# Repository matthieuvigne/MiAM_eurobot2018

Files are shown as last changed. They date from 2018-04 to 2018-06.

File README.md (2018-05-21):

# MiAM_eurobot2018
## Electronics and code of MiAM's robot for Eurobot 2018.

2018 was the first year of MiAM, a French team of former students from MINES ParisTech and Arts et Métiers schools. The team ranked 20th in the Coupe de France. 

See [MiAM website](https://www.miam-robotique.fr/) (in French).

### Contents
 - **Electronics**: component list, PCB and wiring diagram. 
 - **Code_BBB**: the robot code, running on the robot Beaglebone Black processor.

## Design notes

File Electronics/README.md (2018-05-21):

# Electronics Folder

This folder contains files related to the robot electronics: PCB and wiring.

For PCB creation, the free software  [Designspark 8.0](https://www.rs-online.com/designspark/pcb-download-and-installation) was used.

### GlobalArchitecture

A global electrical diagram of the robot, showing the full architecture. All the components are represented, along with wiring links between them.

### Libraries
This folder contains two PCB component libraries used in the main PCB:
 - pinheader : this library contains many footprints for 2.54mm-spaced standard pin headers.
 - Eurobot : a miscellaneous library containing all the custom components used, or that  had been used for previous PCB for Eurobot.
 
To add these libraries to Designspark, go to Libraries (Ctrl + L), Folders, Add and add the path to the Libraries folder.

### BeageboneCape

This is the main (and only) PCB realized this year. It is a cape covering the Beaglebone (like an Arduino shield), responsible for all the interface between the Beaglebone
and the other components, as well as power distribution. See BeagleboneCape.sch and BeagleboneCape.pcb for schematic and layout, respectively.

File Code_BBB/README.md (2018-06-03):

# Code_BBB
This folder contains all the code of the on-board Beaglebone of the robot.
This code, written entirely in C, is organished around a library, named BBBEurobot, that implements all low-level
functionalities needed to use the robot (mainly sensor and motor communication handling, and GPIO/ADC access). This library is 
generic, and could be reused for other projects.

Two other projects use this library: 
 - TestSensors: a simple sensor test. This code tests all the sensors of the robot, both for code debugging and wiring testing purposes.
 - EurobotCode: the main code of the robot, used for Eurobot itself.

## Compiling this code

This code is packaged in such a way as to be cross-compiled from a PC. Cross-compiling indeed has several advantages, the main
one being that there is no need to copy the source to the Beaglebone, thus preventing any temptation to developed on the board itself
(which can be a bad idea if for instance the Beaglebone dies - due to a USB cable short-circuit, I once lost code that way), and making
it very easy to replace the Beaglebone by any other. Other advantages include faster compilation, and the possibility to test compilation
without any access to the Beaglebone.

This code relies on the [glib](https://developer.gnome.org/glib/) - this choice was made to have a single, unified external library for the whole code.
Thus, to cross-compile this code, one needs:

 - a C cross compiler targeting arm platforms.
 - the glib-2.0 library, cross-compiled.

To obtain this, you may do you own setup, or follow the provided guide in ARMCrossCompilationSetup.pdf.

*Note: this identical setup can be used for cross-compiling C code to a Raspberry Pi, as it is also an arm processor.*

## Compiling and installing the BBBEurobot library.

This library, like the rest of this code, is packaged using cmake. To install it to the folder `<installPath>`, simply run:

```
	cmake /path/to/BBBEurobot -DCMAKE_INSTALL_PREFIX=<installPath>
	make
	make install
```

Once installed, this library can be imported using pkg-config. During install, the pkg-config file `BBBEurobot.pc` is installed in 
`<installPath>/lib/pkgconfig` : this path must thus be added to the `PKG_CONFIG_PATH` variable. To do so, open your `.bashrc` file

```
gedit ~/.bashrc
```

and append the following line :

```
export PKG_CONFIG_PATH=<installPath>/lib/pkgconfig
```

Remember to `source ~/.bashrc` before use.

There is a doxygen documentation for this library in `BBBEurobot/doc`. Simply run `make_documentation.sh` to generate it.

## Running code of the Beaglebone.

Obviously, the code we have written aims at using the BeagleBone GPIOs and serial ports. To access these ports, the Beaglebone needs a 
device tree overlay (DTO) file to enable these ports.
A DTO file for BBB-Eurobot, enabeling all the ports exposed on the PCB (plus UART4, which is needed to talk to the servo driver - it wasn't planned
on the PCB but a wire can easily be solder to make this connection. Note that you need a 3.3V to 5V converter).

This file is called Eurobot-00A0.dts, and can be found in the library folder (BBB-Eurobot). To use it, copy this file to the Beaglebone, 
then compile it and copy it to /lib/firmware:

```
	dtc -O dtb -o Eurobot-00A0.dtbo -b 00 -@ Eurobot-00A0.dts
	cp Eurobot-00A0.dtbo /lib/firmware
```

Now doing ```echo Eurobot > /sys/devices/bone_capemgr.9/slots``` enables all these ports for the duration of the current boot (this is done internally by BBB-Eurobot).

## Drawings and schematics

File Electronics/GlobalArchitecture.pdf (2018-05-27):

# MiAM Robot electrical architecture

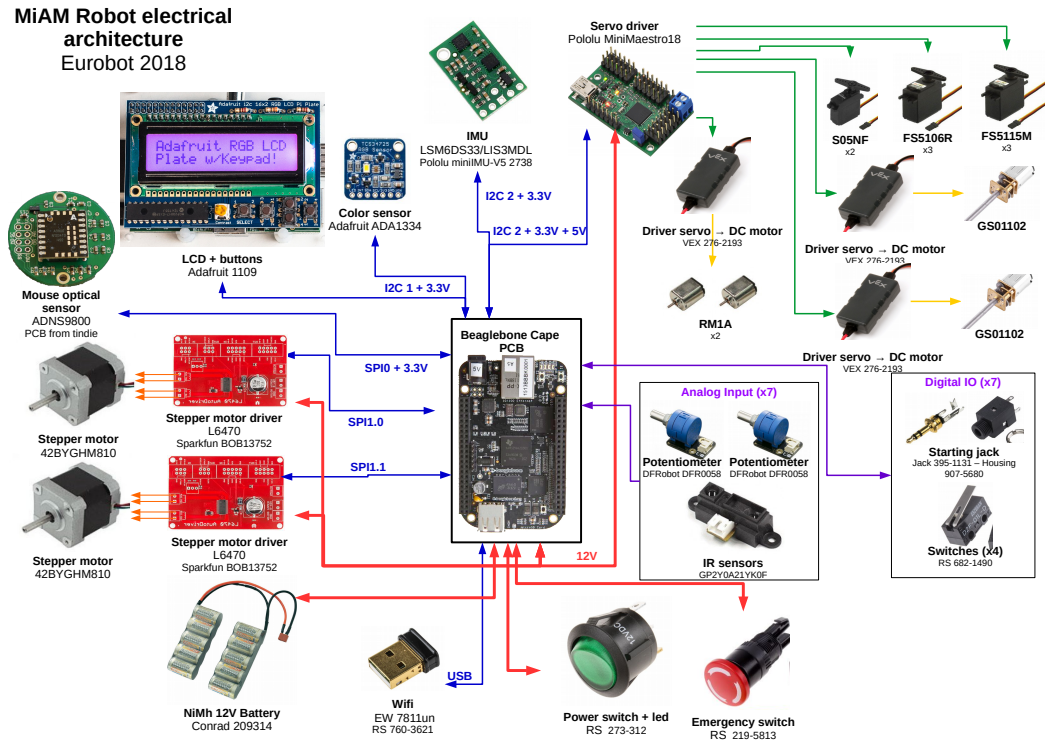
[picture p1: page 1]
IMU LSM6DS33/LIS3MDL Pololu miniIMU-V5 2738; Eurobot 2018; Stepper motor 42BYGHM810; L6470 Sparkfun BOB13752; Beaglebone Cape PCB; Wifi EW 7811un RS 760-3621; LCD + buttons Adafruit 1109; Emergency switch RS 219-5813; SPI0 + 3.3V; SPI1.0; SPI1.1; USB; Servo driver Pololu MiniMaestro18; Digital IO (x7); Analog Input (x7); VEX 276-2193; Starting jack Jack 395-1131 – Housing 907-5680; Potentiometer DFRobot DFR0058; Switches (x4) RS 682-1490; NiMh 12V Battery Conrad 209314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

Driver servo → DC motor

Mouse optical
sensor
ADNS9800
PCB from tindie

Stepper motor driver

Power switch + led

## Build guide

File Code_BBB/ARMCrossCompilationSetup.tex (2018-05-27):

\documentclass[a4paper,11pt]{article}
\usepackage[T1]{fontenc}
\usepackage[utf8]{inputenc}
\usepackage{lmodern}
\usepackage[english]{babel}
\usepackage{hyperref}
\usepackage{listings}

%listings settings
\lstset{
  basicstyle=\ttfamily,
  columns=fullflexible,
  frame=leftline,
  rulecolor=\color{red},
  framerule=2pt,
  xleftmargin=15pt,
  breaklines=true
}

\hypersetup{
  colorlinks   = true, %Colours links instead of ugly boxes
  urlcolor     = blue, %Colour for external hyperlinks
  linkcolor    = black, %Colour of internal links
  citecolor   = black %Colour of citations
}

\title{Cross-compilation environment setup.}
\author{Matthieu Vigne}

\begin{document}
\maketitle
\tableofcontents
\section{Introduction}

\par This guide explains how to setup a cross-compilation environment on a Linux PC (Fedora or Debian/Ubunu) to compile our code, i.e. the BBBEurobot library. This setup works for compiling code to a Beaglebone Black, and to a Raspberry Pi as well.
Three things are needed to cross-compile this code:

 - a C compiler targeting the \emph{armhf} platform, called \textbf{gcc-arm-linux-gnueabihf}.
 
 - a cross-compiled version of the glib, used by our code.
 
 - a renamed \emph{pkg-config} file to load the cross-compiled glib when compiling.
 
\section{Debian setup}

These instructions were tested on Debian 8 (Jessie) in 2015. The setup for Ubuntu is probably quite similar.

Setup on Debian is quite fast, as the official repo already have the compiler and a cross-compiled glib. The only step needed is to tell \emph{apt} to add the arm platform, then install the packages as usual:

\begin{lstlisting}[]
sudo dpkg --add-architecture armhf
sudo apt-get update
sudo apt-get install gcc-arm-linux-gnueabihf
sudo apt-get install libglib2.0-dev:armhf
\end{lstlisting}

Now everything is installed, but there is one last setup step needed: link to the \emph{pkg-config} file of the glib. Since it has the same name as the one installed for your system library version, we will rename it to prevent any conflict. To keep things clear, I advise you modify (freely) the \emph{Name:} and \emph{Description:} fields of this file, \emph{/usr/lib/arm-linux-gnueabihf/pkgconfig/glib-2.0.pc} though for instance the following command:

\begin{lstlisting}
sudo nano /usr/lib/arm-linux-gnueabihf/pkgconfig/glib-2.0.pc
\end{lstlisting}

Then, simply copy this file to the default \emph{pkg-config} search path, renaming it:

\begin{lstlisting}[]
sudo mv /usr/lib/arm-linux-gnueabihf/pkgconfig/glib-2.0.pc /usr/share/pkgconfig/armglib-2.0.pc
\end{lstlisting}

To check that everything works correctly, type:

\begin{lstlisting}[]
pkg-config --list-all | grep arm
\end{lstlisting}

This should give you the \emph{armglib-2.0} library, with the name and description you previously entered.

\section{Fedora setup}

These instructions were tested in Febuary 2018 on Fedora 27.

Contrary to Debian, the official Fedora repo do not contain either the compiler nor the cross-compiled glib. We will get the compiler from an unofficial Copr repo, and then cross-compile the glib from source.

First, install the compiler and cross-compiled glibc (for basic C functions: this is a dependency of glib) using:

\begin{lstlisting}
sudo dnf copr enable lantw44/arm-linux-gnueabihf-toolchain
sudo dnf install arm-linux-gnueabihf-gcc arm-linux-gnueabihf-glibc
\end{lstlisting}

In order to compile the glib, we must first install its dependencies.

The firs is libffi: get the latest version from  \href{https://sourceware.org/libffi/}{https://sourceware.org/libffi/} (v 3.2.1 in Febuary 2018), decompress it, then run from the source folder:

\begin{lstlisting}[]
./configure --host=arm-linux-gnueabihf --prefix=/usr/arm-linux-gnueabihf/sys-root/
make
sudo make install
\end{lstlisting}

The first line configures the build, telling the system to cross-compile the library using the cross-compiler instead of system gcc, and to install it in \emph{/usr/arm-linux-gnueabihf/sys-root/}, the path used on install of the compiler and glibc. Then we compile and install the library.

\emph{Note: for faster compilation, you can append \emph{-jN} to the make instruction, where N is the number of process being run in parallel.}

The second dependancy is the zlib (\href{http://www.zlib.net/}{http://www.zlib.net/}, v 1.2.11 in Febuary 2018), installed with the same process:
\begin{lstlisting}[]
CC=arm-linux-gnueabihf-gcc ./configure --prefix=/usr/arm-linux-gnueabihf/sys-root/
make
sudo make install
\end{lstlisting}

Finally, download the glib \href{http://ftp.gnome.org/pub/GNOME/sources/glib/}{http://ftp.gnome.org/\\pub/GNOME/sources/glib/} (v 2.55.1 in Febuary 2018). Go to the parent of the source directory (i.e. where you uncompressed the archive), create a build folder, in which we place a config file \emph{arm.cache}:

\begin{lstlisting}
mkdir build
cd build
gedit arm.cache
\end{lstlisting}

Copy the following content in \emph{arm.cache}:
\begin{lstlisting}[caption= File arm.cache]
glib_cv_long_long_format=ll
glib_cv_stack_grows=no
glib_cv_uscore=yes
ac_cv_func_posix_getpwuid_r=no
ac_cv_func_posix_getgrgid_r=no
LIBFFI_CFLAGS="-I/usr/arm-linux-gnueabihf/sys-root/lib/libffi-3.2.1/include"
LIBFFI_LIBS="-L/usr/arm-gnueabihf/sys-root/lib -lffi"
ZLIB_CFLAGS="-I/usr/arm-linux-gnueabihf/sys-root/include"
ZLIB_LIBS="-L/usr/arm-linux-gnueabihf/sys-root/lib -lz"
\end{lstlisting}

Now, configure the build using the given \emph{arm.cache}:

\begin{lstlisting}[]
../glib-2.55.1/configure --host=arm-linux-gnueabihf --prefix=/usr/arm-linux-gnueabihf/sys-root/ --cache-file=./arm.cache --with-pcre --enable-libmount=no
make
sudo make install
\end{lstlisting}

Comments: the option --with-pcre tells the configuration script to use internally-package pcre library. --enable-libmount=no disables libmount, a library used for disk mounting that we won't be using on the Beaglebone, and hence that wasn't installed (it can otherwise be installed using the same process as before).

Now everything is installed, but there is one last setup step needed: link to the \emph{pkg-config} file of the glib. Since it has the same name as the one installed for your system library version, we will rename it to prevent any conflict. To keep things clear, I advise you modify (freely) the \emph{Name:} and \emph{Description:} fields of this file, \emph{/usr/arm-linux-gnueabihf/sys-root/lib/pkgconfig/glib-2.0.pc} though for instance the following command:

\begin{lstlisting}
sudo nano /usr/arm-linux-gnueabihf/sys-root/lib/pkgconfig/glib-2.0.pc
\end{lstlisting}

Then, simply copy this file to the default \emph{pkg-config} search path, renaming it:

\begin{lstlisting}[]
sudo mv /usr/arm-linux-gnueabihf/sys-root/lib/pkgconfig/glib-2.0.pc /usr/share/pkgconfig/armglib-2.0.pc
\end{lstlisting}

To check that everything works correctly, type:

\begin{lstlisting}[]
pkg-config --list-all | grep arm
\end{lstlisting}

This should give you the \emph{armglib-2.0} library, with the name and description you previously entered.

\end{document}

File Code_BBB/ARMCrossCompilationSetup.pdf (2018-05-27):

Cross-compilation environment setup.

Matthieu Vigne

May 27, 2018

## Contents

1 Introduction | 1
2 Debian setup | 1
3 Fedora setup | 2

## 1 Introduction

This guide explains how to setup a cross-compilation environment on a Linux PC (Fedora or Debian/Ubunu) to compile our code, i.e. the BBBEurobot library. This setup works for compiling code to a Beaglebone Black, and to a Raspberry Pi as well. Three things are needed to cross-compile this code:
- a C compiler targeting the armhf platform, called gcc-arm-linux-gnueabihf.
- a cross-compiled version of the glib, used by our code.
- a renamed pkg-config file to load the cross-compiled glib when compiling.

## 2 Debian setup

These instructions were tested on Debian 8 (Jessie) in 2015. The setup for Ubuntu is probably quite similar.
Setup on Debian is quite fast, as the official repo already have the compiler and a cross-compiled glib. The only step needed is to tell apt to add the arm platform, then install the packages as usual:

sudo dpkg --add-architecture armhf
sudo apt-get update
sudo apt-get install gcc-arm-linux-gnueabihf sudo apt-get install libglib2.0-dev:armhf

1

Now everything is installed, but there is one last setup step needed: link to the pkg-config file of the glib. Since it has the same name as the one installed for your system library version, we will rename it to prevent any conflict. To keep things clear, I advise you modify (freely) the Name: and Description: fields of this file, /usr/lib/arm-linux-gnueabihf/pkgconfig/glib-2.0.pc though for instance the following command:

sudo nano /usr/lib/arm-linux-gnueabihf/pkgconfig/glib-2.0.pc

Then, simply copy this file to the default pkg-config search path, renaming it:

sudo mv /usr/lib/arm-linux-gnueabihf/pkgconfig/glib-2.0.pc / usr/share/pkgconfig/armglib-2.0.pc

To check that everything works correctly, type:

pkg-config --list-all | grep arm

This should give you the armglib-2.0 library, with the name and description you previously entered.

## 3 Fedora setup

These instructions were tested in Febuary 2018 on Fedora 27.
Contrary to Debian, the official Fedora repo do not contain either the compiler nor the cross-compiled glib. We will get the compiler from an unofficial Copr repo, and then cross-compile the glib from source.
First, install the compiler and cross-compiled glibc (for basic C functions: this is a dependency of glib) using:

sudo dnf copr enable lantw44/arm-linux-gnueabihf-toolchain sudo dnf install arm-linux-gnueabihf-gcc arm-linux-gnueabihf -glibc

In order to compile the glib, we must first install its dependencies.
The firs is libffi: get the latest version from https://sourceware.org/libffi/(v 3.2.1 in Febuary 2018), decompress it, then run from the source folder:

./configure --host=arm-linux-gnueabihf --prefix=/usr/armlinux-gnueabihf/sys-root/
make
sudo make install

The first line configures the build, telling the system to cross-compile the library using the cross-compiler instead of system gcc, and to install it in /usr/arm-linux-gnueabihf/sys-root/, the path used on install of the compiler and glibc. Then we compile and install the library.
Note: for faster compilation, you can append -jN to the make instruction, where N is the number of process being run in parallel.

2

The second dependancy is the zlib (http://www.zlib.net/, v 1.2.11 in Febuary 2018), installed with the same process:

CC=arm-linux-gnueabihf-gcc ./configure --prefix=/usr/armlinux-gnueabihf/sys-root/
make
sudo make install

Finally, download the glib http://ftp.gnome.org/pub/GNOME/sources/glib/ (http://ftp.gnome.org/pub/GNOME/sources/glib/) (v 2.55.1 in Febuary 2018). Go to the parent of the source directory (i.e. where you uncompressed the archive), create a build folder, in which we place a config file arm.cache:

mkdir build
cd build
gedit arm.cache

Copy the following content in arm.cache:

Listing 1: File arm.cache

glib_cv_long_long_format=ll glib_cv_stack_grows=no
glib_cv_uscore=yes
ac_cv_func_posix_getpwuid_r=no ac_cv_func_posix_getgrgid_r=no LIBFFI_CFLAGS="-I/usr/arm-linux-gnueabihf/sys-root/lib/ libffi-3.2.1/include"
LIBFFI_LIBS="-L/usr/arm-gnueabihf/sys-root/lib -lffi" ZLIB_CFLAGS="-I/usr/arm-linux-gnueabihf/sys-root/include" ZLIB_LIBS="-L/usr/arm-linux-gnueabihf/sys-root/lib -lz"

Now, configure the build using the given arm.cache:

../glib-2.55.1/configure --host=arm-linux-gnueabihf --prefix =/usr/arm-linux-gnueabihf/sys-root/ --cache-file=./arm. cache --with-pcre --enable-libmount=no
make
sudo make install

Comments: the option –with-pcre tells the configuration script to use internally-package pcre library. –enable-libmount=no disables libmount, a library used for disk mounting that we won’t be using on the Beaglebone, and hence that wasn’t installed (it can otherwise be installed using the same process as before).
Now everything is installed, but there is one last setup step needed: link to the pkg-config file of the glib. Since it has the same name as the one installed for your system library version, we will rename it to prevent any conflict. To keep things clear, I advise you modify (freely) the

3

Name: and Description: fields of this file, /usr/arm-linux-gnueabihf/sys-root/lib/pkgconfig/glib-2.0.pc though for instance the following command:

sudo nano /usr/arm-linux-gnueabihf/sys-root/lib/pkgconfig/ glib-2.0.pc

Then, simply copy this file to the default pkg-config search path, renaming it:

sudo mv /usr/arm-linux-gnueabihf/sys-root/lib/pkgconfig/glib -2.0.pc /usr/share/pkgconfig/armglib-2.0.pc

To check that everything works correctly, type:

pkg-config --list-all | grep arm

This should give you the armglib-2.0 library, with the name and description you previously entered.

4

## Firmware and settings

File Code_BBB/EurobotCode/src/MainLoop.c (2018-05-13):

/// \file MainLoop.c
/// \brief This file implements the main function, as well as several other features.
///
/// \details We use the glib for event handling. The main loop thus consists in initializing the robot,
///			 starting the auxiliary threads, and then running a GMainLoop with timeout functions.
///			 One timeout function is responsible for checking the infrared sensors - camera wifi communication will
///			 also be done by a callback function.
///
///			 This file includes:
///				- The main() function.
///				- Functions to check on the infrareds sensors.
///				- The heartbeat thread.
///				- The timer thread.

#include "Robot.h"
#include "MotionController.h"
#include "Localisation.h"
#include "Strategy.h"
#include "Strategy.h"


// Sensor value threshold to consider a valid detection.
const int IR_FRONT_THRESHOLD = 850;
const int IR_BACK_THRESHOLD = 850;

# define AVR_WIN 10
int frontIR[2][AVR_WIN];
int backIR[2][AVR_WIN];

gboolean robot_disableIRWater = FALSE;
gboolean robot_disableIROnStartup = FALSE;
GIOChannel *irLogFile = NULL;

gboolean enableIR()
{
	robot_disableIROnStartup = FALSE;
	return FALSE;
}

/// \brief Check the infrared sensors for an obstacle
/// \details This function is called by the main loop in a timeout.
/// \return TRUE, to continue the timeout.
gboolean checkInfrarouge()
{
	if(robot_disableIROnStartup)
	{
		robot_IRDetectionBack = FALSE;
		robot_IRDetectionFront = FALSE;
		return TRUE;
	}
	// Get IR values, filter them using a moving average, then update variable and led status accordingly.
	int backRight = gpio_analogRead(CAPE_ANALOG[3]);
	int backLeft = gpio_analogRead(CAPE_ANALOG[4]);

	for(int i = 1; i < AVR_WIN; i++)
	{
		backIR[0][i-1] = backIR[0][i];
		backIR[1][i-1] = backIR[1][i];
	}
	backIR[0][AVR_WIN-1] = backRight;
	backIR[1][AVR_WIN-1] = backLeft;
	double backRightAverage = 0, backLeftAverage = 0;
	for(int i = 0; i < AVR_WIN; i++)
	{
		backRightAverage += backIR[0][i];
		backLeftAverage += backIR[1][i];
	}
	backRightAverage /= (float)(AVR_WIN);
	backLeftAverage /= (float)(AVR_WIN);

	gboolean sensorValue = backLeftAverage > IR_BACK_THRESHOLD;
	// Disable this IR sensor given that the water-opening arm is in front of it in this position.
	if(!robot_disableIRWater)
		sensorValue |= backRightAverage > IR_BACK_THRESHOLD;

	robot_IRDetectionBack = sensorValue;

	int frontRight = gpio_analogRead(CAPE_ANALOG[2]);
	int frontLeft = gpio_analogRead(CAPE_ANALOG[5]) * 1.1;


	for(int i = 1; i < AVR_WIN; i++)
	{
		frontIR[0][i-1] = frontIR[0][i];
		frontIR[1][i-1] = frontIR[1][i];
	}
	frontIR[0][AVR_WIN-1] = frontRight;
	frontIR[1][AVR_WIN-1] = frontLeft;
	double frontRightAverage = 0, frontLeftAverage = 0;
	for(int i = 0; i < AVR_WIN; i++)
	{
		frontRightAverage += frontIR[0][i];
		frontLeftAverage += frontIR[1][i];
	}
	frontRightAverage /= (float)(AVR_WIN);
	frontLeftAverage /= (float)(AVR_WIN);

	sensorValue = (frontRightAverage > IR_FRONT_THRESHOLD) ||
	              (frontLeftAverage > IR_FRONT_THRESHOLD);

	robot_IRDetectionFront = sensorValue;
	// Turn on red led if we see something on any sensor.
	if(robot_IRDetectionBack || robot_IRDetectionFront)
		gpio_digitalWrite(CAPE_LED[1], 1);
	else
		gpio_digitalWrite(CAPE_LED[1], 0);
	// Log results.
	//~ if(irLogFile != NULL)
	//~ {
		//~ gchar *line = g_strdup_printf("%d,%d,%d,%d,%d,%d,%f,%f,%f,%f\n", frontRight, frontLeft, backRight, backLeft,
		                                                     //~ robot_IRDetectionFront, robot_IRDetectionBack,
		                                                     //~ frontRightAverage, frontLeftAverage, backRightAverage, backLeftAverage);
		//~ g_io_channel_write_chars(irLogFile, line, -1, NULL, NULL);
		//~ g_io_channel_flush (irLogFile, NULL);
		//~ g_free(line);
	//~ }
	return TRUE;
}


GTimer *timerMain;

// Function that stops the robot.
gboolean stop_robot()
{
	printf("End of match, time: %f\n", g_timer_elapsed(timerMain, NULL));
	// Kill startegy thread to stop the motors.
	pthread_kill(strategyThread, SIGINT);
	g_usleep(500000);
	exit(0);

	return TRUE;
}

// Heartbeat thread.
// This thread simply blinks a cape led, to show that the code is still running
void *heartbeatThread()
{
	while(TRUE)
	{
		g_usleep(200000);
		gpio_digitalWrite(CAPE_LED[0], 1);
		g_usleep(200000);
		gpio_digitalWrite(CAPE_LED[0], 0);
	}
}

gboolean initRobot()
{
	gboolean isInitSuccessful = TRUE;
	gboolean initLCD = lcd_initDefault(&robotLCD, &I2C_2);
	if(!initLCD)
	{
		printf("Could not detect LCD display\n");
		// Can't do much more that turning on the led if we don't have the LCD display.
		gpio_digitalWrite(CAPE_LED[1], 1);
		g_usleep(1000000);
	}
	isInitSuccessful &= initLCD;

	gboolean initIMU = imu_initDefault(&robotIMU, &I2C_1, FALSE);
	if(!initIMU)
	{
		printf("Could not detect IMU\n");
		lcd_setText(robotLCD, "IMU init failed", 0);
		lcd_setBacklight(robotLCD, TRUE, FALSE, FALSE);
		g_usleep(1000000);
	}
	isInitSuccessful &= initIMU;

	gboolean initServo = maestro_initDefault(&robotServo, "/dev/ttyO4");
	if(!initServo)
	{
		printf("Could not talk to servo driver\n");
		lcd_setText(robotLCD, "Servo init failed", 0);
		lcd_setBacklight(robotLCD, TRUE, FALSE, FALSE);
		g_usleep(1000000);
	}
	else
		servo_initPosition();
	isInitSuccessful &= initServo;

	gboolean initMouse = ANDS9800_init(&robotMouseSensor, SPI_0);
	if(!initMouse)
	{
		printf("Could not detect mouse sensor\n");
		lcd_setText(robotLCD, "Mouse init failed", 0);
		lcd_setBacklight(robotLCD, TRUE, FALSE, FALSE);
		g_usleep(1000000);
	}
	isInitSuccessful &= initMouse;

	// Color sensor is unsused in this version of the code.
	//~ gboolean initColor = colorSensor_init(&robotColorSensor, &I2C_1);
	//~ if(!initColor)
	//~ {
		//~ printf("Could not detect color sensor\n");
		//~ lcd_setText(robotLCD, "Color init failed", 0);
		//~ lcd_setBacklight(robotLCD, TRUE, FALSE, FALSE);
		//~ g_usleep(1000000);
	//~ }
	//~ else
	//~ {
		//~ // Setup sensor
		//~ colorSensor_setGain(robotColorSensor, TCS34725_GAIN_16X);
		//~ colorSensor_setIntegrationTime(robotColorSensor, 5);
	//~ }
	//~ isInitSuccessful &= initColor;

	// Try motor init - we are more likely to get a failure here, so print in on the first line.
	gboolean initMotor = motion_initMotors();
	if(!initMotor)
	{
		printf("Could not init motors: are they turned on ?\n");
		lcd_setText(robotLCD, "Motor init failed", 0);
		lcd_setBacklight(robotLCD, TRUE, TRUE, FALSE);
	}
	isInitSuccessful &= initMotor;

	if(isInitSuccessful)
	{
		printf("Init successful\n");
		lcd_setText(robotLCD, "Robot init done", 0);
		lcd_setBacklight(robotLCD, FALSE, TRUE, FALSE);
	}
	g_usleep(1000000);
	return isInitSuccessful;
}

// Wait for match start, returns robot side (TRUE = RIGHT, FALSE = LEFT)
gboolean waitForStart(gboolean isInitDone)
{
	// Wait for staring jack to be plugged in.
	if(gpio_digitalRead(CAPE_DIGITAL[0]) == 1)
	{
		printf("Waiting for jack to be plugged in\n");
		lcd_setText(robotLCD, "Waiting for jack", 1);
		while(gpio_digitalRead(CAPE_DIGITAL[0]) == 1)
			g_usleep(50000);
		printf("Jack plugged in, waiting for match start\n");
		// Prevent unwanted start from switch bounce.
		g_usleep(1000000);
	}
	if(isInitDone)
		lcd_setText(robotLCD, "Ready to start", 0);

	gboolean isRightSide = FALSE;
	gboolean oldSide = FALSE;
	lcd_setText(robotLCD, "     GREEN     >", 1);
	lcd_setBacklight(robotLCD, FALSE, TRUE, FALSE);

	gboolean motorReleased = TRUE;
	motion_releaseMotors();
	while(gpio_digitalRead(CAPE_DIGITAL[0]) == 0)
	{
		if(!isInitDone)
		{
			// Retry motor init.
			isInitDone = motion_initMotors();
			if(isInitDone)
			{
				servo_initPosition();
				printf("Motor init successful\n");
				lcd_setText(robotLCD, "Motor init done", 0);
				g_usleep(1000000);
				lcd_setText(robotLCD, "Ready to start", 0);
			}
		}

		if(lcd_isButtonPressed(robotLCD, LCD_BUTTON_RIGHT))
		{
			oldSide = isRightSide;
			isRightSide = TRUE;
		}

		if(lcd_isButtonPressed(robotLCD, LCD_BUTTON_LEFT))
		{
			oldSide = isRightSide;
			isRightSide = FALSE;
		}

		if(lcd_isButtonPressed(robotLCD, LCD_BUTTON_SELECT))
		{
			motorReleased = !motorReleased;
			if(motorReleased)
				motion_releaseMotors();
			else
				motion_stopMotors();
			while(lcd_isButtonPressed(robotLCD, LCD_BUTTON_SELECT))
				g_usleep(20000);
		}

		if(oldSide != isRightSide)
		{
			if(isRightSide)
			{
				lcd_setText(robotLCD, "<    ORANGE     ", 1);
				lcd_setBacklight(robotLCD, TRUE, TRUE, FALSE);
			}
			else
			{
				lcd_setText(robotLCD, "     GREEN     >", 1);
				lcd_setBacklight(robotLCD, FALSE, TRUE, FALSE);
			}
		}
		checkInfrarouge();
		g_usleep(50000);
	}
	return isRightSide;
}

int main(int argc, char **argv)
{
	// Init beaglebone.
	BBB_enableCape();
	// Create a GMainLoop
	GMainLoop* loop = g_main_loop_new(0, 0);
	// Start heartbeat thead.
	g_thread_new("Heartbeat", heartbeatThread, NULL);
	// Init robot hardware.
	gboolean initDone = initRobot();
	// Wait for match to start, redoing motor init if previously failed.
	robot_isOnRightSide = waitForStart(initDone);
	//~ robot_isOnRightSide = FALSE;
	//~ servo_closeClaws();

	// Start match, set timer to 100s.
	timerMain = g_timer_new();
	g_timer_start(timerMain);
	g_timeout_add(100000, stop_robot, NULL);

	// Set robot to initial position: right of the zone, back against the wall.
	startingPosition.x = 60 + CHASSIS_BACK;
	startingPosition.y = 60 + CHASSIS_SIDE;
	startingPosition.theta = 0;
	robot_setPosition(startingPosition);

	// Turn screen backlight to white, display on second line IR sensor status.
	lcd_setBacklight(robotLCD, TRUE, TRUE, TRUE);
	lcd_clear(robotLCD);
	lcd_setText(robotLCD, "Score:          ", 0);
	//~ lcd_setText(robotLCD, "IR F:  B: ", 1);

	// Launch the strategy thread
	g_thread_new("Strategy", strategy_runMatch, NULL);
	g_thread_new("Localisation", localisation_start, NULL);

	// Create IR log file
	gchar *date = g_date_time_format(g_date_time_new_now_local(), "%Y%m%dT%H%M%SZ");
	gchar *filename = g_strdup_printf("logIR%s.csv", date);
	irLogFile = g_io_channel_new_file(filename, "w", NULL);
	gchar *line = g_strdup_printf("IR Log: %s\n", date);
	g_free(date);
	g_free(filename);

	g_io_channel_write_chars(irLogFile, line, -1, NULL, NULL);
	g_io_channel_flush (irLogFile, NULL);
	g_free(line);

	g_io_channel_write_chars(irLogFile, "frontRight,frontLeft,backRight,backLeft,frontStatus,backStatus,frontRightFiltered,frontLeftFiltered,backRightFiltered,backLeftFiltered\n", -1, NULL, NULL);
	g_io_channel_flush (irLogFile, NULL);

	// Timeout functions to check on the infrared sensors.
	robot_disableIROnStartup = TRUE;
	g_timeout_add(10, checkInfrarouge, NULL);
	g_timeout_add(1500, enableIR, NULL);
	// Run glib main loop.
    g_main_loop_run(loop);
	return 0;
}

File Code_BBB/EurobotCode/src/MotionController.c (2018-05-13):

#include "Robot.h"
#include "MotionController.h"

// Max robotMotors speed and acceleration, in half counts / s.
const int MOTOR_MAX_SPEED = 690;
const int MOTOR_MAX_ACCELERATION = 500;

// Motor current profile constants, for the 42BYGHW810 robotMotors, 2.0A - these values are computed using ST dSPIN utility.
const int MOTOR_KVAL_HOLD = 0x25;
const int MOTOR_BEMF[4] = {0x36, 0x172E, 0xC, 0x33};


// Generic implementation of a PID controller.
typedef struct{
	double integral; 	///< Integral value.
	double maxIntegral;	///< Maximum value of the integral feedback, i.e Ki * integral (to prevent windup).
	double Kp;			///< Proportional gain.
	double Kd;			///< Derivative gain.
	double Ki;			///< Integral gain.
}PID;

gboolean stopOnSwitch = FALSE;

// Compute next value of PID command, given the new error and the elapsed time.
double PID_computeValue(PID *pid, double positionError, double velocityError, double dt)
{
	// Compute and saturate integral.
	pid->integral += positionError * dt;
	// Prevent division by 0.
	if(ABS(pid->Ki) > 1e-6)
	{
		if(pid->Ki * pid->integral > pid->maxIntegral)
			pid->integral = pid->maxIntegral / pid->Ki;
		if(pid->Ki * pid->integral < -pid->maxIntegral)
			pid->integral = -pid->maxIntegral / pid->Ki;
	}
	// Output PID command.
	return pid->Kp * (positionError + pid->Kd * velocityError + pid->Ki * pid->integral);
}



// Trajectory for rotation motion: a velocity trapezoid.
// This function computes trajectory position and velocity at time t.
void rotationTrajectory(double targetAngle, double time, double *position, double *velocity)
{
	// Rotation trajectory velocity parameters.
	double ROTATION_MAX_VELOCITY = 0.9 * MOTOR_MAX_SPEED * STEP_TO_SI / ROBOT_WIDTH * 2.0;
	double ROTATION_MAX_ACCELERATION = 6.0 * MOTOR_MAX_ACCELERATION * STEP_TO_SI / ROBOT_WIDTH * 2.0;
	int sign = 1;
	if(targetAngle < 0)
	{
		sign = -1;
		targetAngle = -targetAngle;
	}

	double rotationDistanceToFullSpeed = ROTATION_MAX_VELOCITY * ROTATION_MAX_VELOCITY / ROTATION_MAX_ACCELERATION / 2.0;
	if(targetAngle < rotationDistanceToFullSpeed)
	{
		// Motion is too short to reach a constant velocity profile: just do an acceleration and deceleration phase.
		double switchTime = sqrt(targetAngle / ROTATION_MAX_ACCELERATION);
		if(time < switchTime)
		{
			*velocity = ROTATION_MAX_ACCELERATION * time;
			*position = ROTATION_MAX_ACCELERATION * time * time / 2.0;
		}
		else
		{

			*velocity = ROTATION_MAX_ACCELERATION * (2 * switchTime - time);
			*position = targetAngle / 2.0 +
			            ROTATION_MAX_ACCELERATION * switchTime * (time - switchTime) -
			            ROTATION_MAX_ACCELERATION * (time - switchTime) * (time - switchTime) / 2.0;
		}
	}
	else
	{
		// We have time for full acceleration.
		double accelerationTime = ROTATION_MAX_VELOCITY / ROTATION_MAX_ACCELERATION;
		double constantVelocityTime = accelerationTime +
		                             (targetAngle - 2 * rotationDistanceToFullSpeed) / ROTATION_MAX_VELOCITY;
		if(time < accelerationTime)
		{
			// Acceleration
			*velocity = ROTATION_MAX_ACCELERATION * time;
			*position = ROTATION_MAX_ACCELERATION * time * time / 2.0;
		}
		else if(time < constantVelocityTime)
		{
			// Constant velocity.
			*velocity = ROTATION_MAX_VELOCITY;
			*position = rotationDistanceToFullSpeed +
			            ROTATION_MAX_VELOCITY * (time - accelerationTime);
		}
		else
		{
			*velocity = ROTATION_MAX_VELOCITY - ROTATION_MAX_ACCELERATION * (time - constantVelocityTime);
			*position = targetAngle - rotationDistanceToFullSpeed +
			            ROTATION_MAX_VELOCITY * (time - constantVelocityTime) -
			            ROTATION_MAX_ACCELERATION * (time - constantVelocityTime) * (time - constantVelocityTime) / 2.0;
		}
	}
	// Clamp trajectory at end.
	if(*position > targetAngle || *velocity < 0.0)
	{
		*position = targetAngle;
		*velocity = 0;
	}
	// Restore sign.
	*position = sign * (*position);
	*velocity = sign * (*velocity);
}

// Helper function: compute rotation angle to go to a specified point.
// The angle returned is in ]-pi,pi]
double computeRotationAngle(RobotPosition start, RobotPosition end)
{
	// Don't rotate if motion is too small.
	if(ABS(end.x - start.x) < 0.002 && ABS(end.y - start.y) < 0.002)
		return 0;
	// Switch y axis sign, because frame is indirect.
	end.y = -end.y;
	start.y = -start.y;

	// Get angle between start and end, between 0 and 2 * PI
	double deltax = end.x - start.x;
	double startEndAngle = 0.0;
	if(deltax==0)
	{
		if(end.y < start.y)
			startEndAngle = 3.0 * G_PI/2.0;
		else
			startEndAngle =  G_PI/2.0;
	}
	else
	{
		if(deltax > 0)
			startEndAngle =  atan( (end.y - start.y)/(end.x - start.x));
		else
			startEndAngle =  G_PI + atan( (end.y - start.y)/(end.x - start.x));
	}
	// Find the rotation angle amount.
	double rotationAngle = startEndAngle - start.theta;
	while(rotationAngle >= G_PI)
		rotationAngle -= 2 * G_PI;
	while(rotationAngle < -G_PI)
		rotationAngle += 2 * G_PI;

	return rotationAngle;
}

// Distance from the side of field at which we stop listening to IR sensors while moving.
double BORDER_DEADZONE = 500;

// Check infrared sensor, return TRUE if there is an obstacle on the way.
gboolean checkSensor(gboolean backward)
{
	// Create a fictitious point BORDER_DISTANCE in front of the robot. If this point is outside of
	// the field, we ignore IR sensors to prevent detecting a referee as an obstacle.
	RobotPosition robotViewpoint = robot_getPosition();
	// Going backward: add PI to angle to get the back of the robot.
	if(backward)
		robotViewpoint.theta += G_PI;

	robotViewpoint.x += BORDER_DEADZONE * cos(robotViewpoint.theta);
	// Minus sign: the frame is indirect.
	robotViewpoint.y -= BORDER_DEADZONE * sin(robotViewpoint.theta);

	if(robotViewpoint.x < 0 || robotViewpoint.x > 3000 || robotViewpoint.y < 0 || robotViewpoint.y > 2000)
		return FALSE;
	// Ignore bottom ball catcher.
	if((robotViewpoint.x < 900 && robotViewpoint.x > 400) && robotViewpoint.y > 1800)
		return FALSE;
	if(robotViewpoint.x < 500 && (robotViewpoint.y > 500 && robotViewpoint.y < 1000))
		return FALSE;

	if(backward)
		return robot_IRDetectionBack;
	return robot_IRDetectionFront;
}
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

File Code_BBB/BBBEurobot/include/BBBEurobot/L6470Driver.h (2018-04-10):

/// \file L6470Driver.h
/// \brief Driver for the L6470 stepper motor driver.
///
/// \details This file implements all the functions to talk to the stepper motor controller.
/// 		 It is adapted from Sparkfun's driver for Arduino. All functions are thread-safe.
///	\note	 All functions in this header should be prefixed with L6470_.
#ifndef L6470_DRIVER
#define L6470_DRIVER

	#include <stdint.h>
	#include <glib.h>


	/// L6470 structure.
	typedef struct
	{
		gchar *portName;	///< String representing the name (in the file system) of the SPI port. This must be set by hand before using the structure.
		int port;			///< File descriptor of the SPI port.
		int frequency;		///< SPI clock frequency, in Hz. This is set by default to 800kHz (100000byte/s), but can be changed if needed.
	}L6470;

	/// \brief Initialize the L6470 structure.
	/// \details This function only sets the structure correctly, but does not perform any operation on the
	///          SPI port. For this reason, it cannot detect a configuration failure, and has no return value.
	///
	/// \param[out] l A L6470 structure to use to talk to the targeted motor.
    /// \param[in] portName Name of the port, in the file system (i.e. a string "/dev/spidevx").
    /// \param[in] speed Communication speed.
	void L6470_initStructure(L6470 *l, const gchar *portName);

	/// \brief Initialize the motor driver.
    ///
    /// \details This function prepares the motor driver for motion, by defining the motor speed, acceleration and
    ///          deceleration. It also sets the step mode and the max stall current. Finally, it places the motor
	///			 in high impedance (i.e. free spinning shaft).
    ///
    /// \note   This function does not initialize the L6470 structure.
    /// \param[in] l A valid L6470 structure.
    /// \param[in] maxSpeed Maximum motor speed, in steps/s (from 15.25 to 15610, resolution 15.25 step/s).
    /// \param[in] maxAcceleration Maximum motor acceleration and deceleration, in steps/s^2 (from 14.55 to 59590,
    ///                            resolution 14.55 step/s^2).
	void L6470_initMotion(L6470 l, int maxSpeed, int maxAcceleration);


	/// \brief Define BEMF compensation and target current constants.
    ///
    /// \details This stepper motor includes a back-electromagnetic force compensation. To tune it, it needs informations
    ///		     on the motor. See chip datasheet for more information. ST has released a windows utility to calculate
    ///			 the value of these registers based on information about the motor's parameters and the desired curent.
    ///
    /// \param[in] l A valid L6470 structure.
    /// \param[in] k_hld Value of the SPIN_KVAL_HOLD register.
    /// \param[in] k_mv Value of the SPIN_KVAL_ACC, SPIN_KVAL_DEC and SPIN_KVAL_RUN registers.
    /// \param[in] int_spd Value of the SPIN_INT_SPD register.
    /// \param[in] st_slp Value of the SPIN_ST_SLP register.
    /// \param[in] slp_acc Value of the SPIN_FN_SLP_ACC and SPIN_FN_SLP_DEC registers.
	void L6470_initBEMF(L6470 l, uint32_t k_hld, uint32_t k_mv, uint32_t int_spd, uint32_t st_slp, uint32_t slp_acc);


	/// \brief Read a parameter from the motor controler.
    ///
    /// \param[in] l A valid L6470 structure.
    /// \param[in] param The parameter to read.
    /// \returns The current value of param.
	uint32_t L6470_getParam(L6470 l, uint8_t param);


	/// \brief Get current motor position.
    ///
    /// \param[in] l A valid L6470 structure.
    /// \returns The current motor position, in steps.
	int32_t L6470_getPosition(L6470 l);


	/// \brief Get current motor position.
    ///
    /// \param[in] l A valid L6470 structure.
    /// \returns The current motor speed, in steps/s.
	double L6470_getSpeed(L6470 l);


	// STEP_MODE option values.
	// First comes the "microsteps per step" options...
	typedef enum DSPIN_STEP_MODE_CONST
	{
		dSPIN_STEP_MODE_STEP_SEL    = 0x07,  // Mask for these bits.
		dSPIN_STEP_SEL_1            = 0x00,
		dSPIN_STEP_SEL_1_2          = 0x01,
		dSPIN_STEP_SEL_1_4          = 0x02,
		dSPIN_STEP_SEL_1_8          = 0x03,
		dSPIN_STEP_SEL_1_16         = 0x04,
		dSPIN_STEP_SEL_1_32         = 0x05,
		dSPIN_STEP_SEL_1_64         = 0x06,
		dSPIN_STEP_SEL_1_128        = 0x07

	} DSPIN_STEP_MODE_CONST;

	/// \brief Set motor driver step mode.
	///
	/// \warning After this function call, the value of the position register changes.
    /// \param[in] l A valid L6470 structure.
    /// \param[in] stepMode Target step mode (full step to 1/128th step).
	void L6470_setStepMode(L6470 l, DSPIN_STEP_MODE_CONST stepMode);


	/// \brief Set current motor speed.
    ///
    /// \param[in] l A valid L6470 structure.
    /// \param[in] speed Current motor speed, in steps/s (between -15625 and 156250).
    ///            Value will be clamped internally by the maximum speed.
	void L6470_setSpeed(L6470 l, int speed);


	/// \brief Set motor max speed.
    ///
    /// \param[in] l A valid L6470 structure.
    /// \param[in] maxSpeed Maximum motor speed, in steps/s (from 15.25 to 15610, resolution 15.25 step/s).
    /// \param[in] acc Target motor acceleration, in steps/s^2 (from 14.55 to 59590, resolution 14.55 step/s^2).
    /// \param[in] dec Target motor deceleration, in steps/s^2 (from 14.55 to 59590, resolution 14.55 step/s^2).
	void L6470_setVelocityProfile(L6470 l, int maxSpeed, int accel, int decel);


	/// \brief Perform a soft motor stop.
	/// \details A soft stop means that the motor will decelerate at given deceleration until it stops (contrary to a
	///			 hard stop where the motor stops instantaneously). Only soft stop is exposed to prevent damage to the
	///			 motor.
    ///
    /// \param[in] l A valid L6470 structure.
	void L6470_softStop(L6470 l);


	/// \brief Perform a hard motor stop: motor will try to stop instantaneously.
    /// \note Hard stopping may damage motor or electronics. softStop is the function that should normally be called.
    ///
    /// \param[in] l A valid L6470 structure.
	void L6470_hardStop(L6470 l);


	/// \brief Get the status of the motor controler.
    ///
    /// \param[in] l A valid L6470 structure.
	uint32_t L6470_getStatus(L6470 l);


	/// \brief Get the last error read from the motor controller.
	/// \details If an error is present, it will be printed in the terminal.
    ///
    /// \param[in] l A valid L6470 structure.
	uint32_t L6470_getError(L6470 l);


	/// \brief Place the motor in a high impedance state. The shaft will now spin freely.
    ///
    /// \param[in] l A valid L6470 structure.
	void L6470_highZ(L6470 l);


	/// \brief Move the motor a desired number of steps.
    ///
    /// \param[in] l A valid L6470 structure.
    /// \param[in] pos The number of steps to move the motor (negative means backward motion).
	void L6470_goToPosition(L6470 l, int32_t pos);
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

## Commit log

2017-11-19 [Electronique] Création du dossier Electronique.
    - Mise à jour du README.md pour décrire les dossiers Electronique et
    Programmation (pas encore créé).
    - Ajout des bibliothèques pour l'électronique et de la version de l'an
    passé du circuit BeagleboneCape.
    - Ajout d'un README.md dans le dossier Electronique.
    [BeagleboneCape.sch]
2017-11-21 [ProgrammationBBB] Ajout du dossier ProgrammationBBB
    - Ajout de la bibliothèque BBBEurobot
    - Ajout du programme de test TestADNS (pour démo de l'usage de BBBEurobot et pour un exemple de fichier CMakeLists)
    - Ajout d'un tuto pour la configuration d'un environnement de cross-compilation.
    - Mise à jour du README principal + README dans ProgrammationBBB.
2017-11-27 [Programmation] Ajout du filtre de kalman et mise a jour des CMakeLists
    - Ajout des liens vers libpthread et libmath lors de la compilation.
    - Ajout de l'option make install a TestADNS
    - Cleanup.
    - Ajout du code du filtre de Kalman a BBBEurobot.
2017-12-09 [ProgrammationBBB] Ajout de la documentation et de l'initialisation.
    - Ajout du dossier doc générant une documentation doxygen de BBBEurobot.
    - Ajout de l'overlay Eurobot-00A0.dts pour activer les ports série.
    - Ajout de BBBGpio - gestion des ports série uniquement.
    - Supression de IRReciever (inutile pour le moment).
    - Mise a jour de TestADNS.
2018-01-14 [electronics] Add board schematics.
    - Update Beaglebone cape schematics.
    - Add schematic for external servo handling board.
    - Update PCBs for both boards - preliminary placement, routing not yet
    done.
    [BeagleboneCape.sch, ServoDriver.sch]
2018-01-20 [electronics] First version of board routing and wiring diagram.
    - Full routing of BeagleboneCape.
    - First draft of routing ServoDriver - this still requires work.
    - Add high level wiring diagram.
    - Rename "Bibliotheques" folder to "Libraries".
    [BeagleboneCape.sch, ServoDriver.sch]
2018-01-20 [electronics] Update servoDriver
    - Modify servoDriver to support 16 servos, separated into 2 sets of 8.
    - Update wiring diagram to include starting jack.
    [BeagleboneCape.sch, ServoDriver.sch]
2018-01-21 [electronics] Update after jan. 21th meeting.
    - Add reference for missing components: color sensors, switch, IR...
    - Move ball throwing motors from Beaglebone cape to servo driver (to be
    affected by emergency switch).
    - Add an extra PWM output to Beaglebone cape.
    [BeagleboneCape.sch]
2018-01-25 [BBBEurobot] Add PCAServoDriver, code for the ServoDriver board.
2018-01-27 [BBBEurobot] Rework of I2C-Wrapper.
    Reimplement I2C wrappers to give better debug info, and to be thread-safe even when using several I2C ports.
    This is done by creating a new I2CAdapter structure to link port name and mutex.
    [I2C-Wrapper.c, IMUDriver.c, PCA9635Driver.c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]
2018-01-28 [BBB-Eurobot] Add driver for color sensor. Change types of some I2C functions.
    Most parameters of the I2C drivers should be of type guint8 (i.e. unsigned char i.e. uint8_t) instead of int.
    This was changed in I2C-Wrapper and in some other drivers.
2018-01-29 [BBBEurobot] Add driver for LCD screen. Update documentation.
    Note that the LCD driver is not fully fonctional yet: the screen
    only works with one line activated.
2018-02-08 [BBB-Eurobot] Fix driver for TCS3472 Color Sensor after code testing. Fix bug in BBB_enableCape where early return canceled digital pin configuration.
    [BeagleboneCape.c, TCS3472ColorSensorDriver.c]
2018-02-10 [Electronics] Update board schematics and PCB after board assembly.
    - Fix component footprint error in BeaglebonCape.
    - Fixed labeling error in ServoDriver
    - Updated layout of ServoDriver to place the voltage regulator
    on the side, so as to enable placing a heat sink next to it.
    [BeagleboneCape.sch, ServoDriver.sch]
2018-02-23 [BBB-Eurobot] Update IMU driver to work with Pololu MiniIMU-V5 instead of V3.
    Update DTO file - set I2C frequency to 400kHz instead of 100kHz.
    Fix bug in enabling GPIOs.
    [BeagleboneCape.c, IMUDriver.c]
2018-02-25 [BBBEurobot] Testing of servo driver and analog input code.
    Minor code fixup.
    [BeagleboneCape.c, I2C-Wrapper.c, PCAServoDriver.c]
2018-02-27 [BBB-Eurobot] Fix LCD driver after component test.
    [LCDDriver.c]
2018-03-01 [BBB-Eurobot] Update SPI handling.
    - Modify SPI-related struct. to have default frequency at 800kHz instead
    of taking 'speed' as an argument.
    - Modify ADNS9800 api to be more consistent with the rest of the library.
2018-03-03 [BBB-Eurobot] Release of V1.0
    - The library has been fully tested at least once, except for L6470 driver (but it is similar
    to the one used last year).
    - Added SPI wrapper class, to begin merging the two SPI implementations (WIP).
    - Cape I2C are now I2C adpater directly instead of strings.
2018-03-03 [programming] Added test script for all sensors.
    Add TestSensors code, that test all components of the robot except motors.
    This code tests:
    - digital input and output (leds)
    - analog input
    - IMU
    - Mouse sensor
    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
2018-03-03 [programming] Remove obsolete TestADNS project.
    This project is replaced by the more complete TestSensors project.
    [Main.c]
2018-03-17 [BBB-Eurobot] Full reimplementation of L6470 driver.
    After reading the datasheet, implement SPI communication in a way that is
    more consistent whith what is being asked by the driver.
    The previous code was doing independant SPI operation for each byte transfer,
    while the current code treats one device command as a single transfer.
    The new implementation also ensures zeros are sent when no command is needed,
    removing the frequen "command no exec" error.
    [L6470Driver.c, L6470Driver.h]
2018-03-17 [overlay] Add UART4 to device tree overlay file (for new servo driver).
2018-03-18 [BBBEurobot] Make L6470_getError verbose.
    L6470_getError now prints human-readable errors.
    [L6470Driver.c, L6470Driver.h]
2018-03-23 [BBB-Eurobot] Add driver for Pololu Maestro servo driver board.
    Note that this code only supports writing to the servo board,
    reading functions are not implemented.
2018-04-08 [BBB-Eurobot] Fixup of servo driver.
    Maestro servo driver tested and functional.
    [MaestroServoDriver.c]
2018-04-08 [BBB-Eurobot] Fix minor error in L6470 driver.
    Wrong Command and Bad Command errors returned by the IC are active
    high, unlike the other wich are active low. This wasn't taken
    into account, leading to erronous error messages being printed.
    [L6470Driver.c]
2018-04-10 [BBB-Eurobot] Modify L6470Driver API.
    - Add setStepMode function.
    - Drive now starts in full step mode.
    - L6470_initMotion no longer takes separate accel and decel values.
    [L6470Driver.c, L6470Driver.h]
2018-04-20 [BBB-Eurobot] Add missing implementation of L6470_hardStop
    [L6470Driver.c]
2018-04-20 [eurobotCode] Fix code according to March 4th Skype
    - Fix currentTime & lastTime in MotionController.c
    - Replace timerThread with a g_timeout to end the match
    [MainLoop.c, MotionController.c]
2018-04-20 [Eurobot Code] Many minor code changes.
    - Robot: replace RobotTarget.parameter by RobotTarget.RobotPosition
    - MotionController: change motor current from 1.5A running (1.8 blocked) to 2.0A - 2.1A.
    - Main: add mouse sensor init.
    - Strategy: uncomment testing trajectory.
    [MainLoop.c, MotionController.c, Strategy.c]
2018-04-20 Full rewrite of robot positionning and motion on table.
    The code now has an architecture closer to that of last year, with localisation and
    constrol separated:
    - file Localisation.c implements a thread that runs robot position estimation and logging.
    - file MotionController implements blocking functions for robot motion (rotation, translation,
    goTo).
2018-04-20 [EurobotCode] End of init code, servo testing.
2018-04-20 [EurobotCode] More servo testing and corresponding code.
2018-04-20 [EurobotCode] Add trajectory for rotation.
    Previously, rotations were done using a step input. This is replaced
    by a velocity trapezoid, generating a continuous motion.
    [MotionController.c]
2018-04-20 [EurobotCode] Fixup of motion, wait and infrared.
    Test waitForStart and infrared sensors, fixed code bugs.
    Test trapezoid trajectory for rotation, update PID gains.
    Fix error in computeRotationAngle.
    [MainLoop.c, MotionController.c, Strategy.c]
2018-04-20 [Eurobot] Update strategy and servo motion after further testing. Tune motion controller for better performances.
2018-05-03 [BBB-Eurobot] Bugfix and tunning.
    - Make LCD driver thread safe by adding a mutex when writing a character to the screen.
    - Update Kalman filter gains.
    - Update ADNS9800 sensor.
    [ADNS9800Driver.c, LCDDriver.c]
2018-05-05 [BBB-Eurobot] Raise default L6470 stall and OCD thersholds.
    [L6470Driver.c]
2018-05-06 [EurobotCode] Change the way motors are stopped.
    Previously motion_stopMotors setted them to high-impedence instantaneously,
    thus no braking was applied. This has been fixed.
    Change velocity profile to have stronger deceleration than acceleration.
    [MainLoop.c, MotionController.c, Strategy.c]
2018-05-06 [EurobotCode] Remove logging of unused gyroX and gyroY, add logging of Kalman bias.
2018-05-06 [EurobotCode] Change avoidance so that the robot will not wait for longer than needed. Increase IR reading frequency.
    If two successive readings give a no-robot call, motion can start again.
    [MainLoop.c, MotionController.c]
2018-05-09 [BBB-Eurobot] Ignore stall errors.
    [L6470Driver.c]
2018-05-13 [Eurobot] Code of match 4 - modify IR code.
    IR sensors are now filtered using a moving average filter, instead of waiting
    for consecutive similar values. Add IR log.
2018-05-21 Update all READMEs, translate them all to English.
    Change folder name to English, translate wiring diagram, translate all
    README files.
    [BeagleboneCape.sch, ServoDriver.sch]
2018-05-27 [Electronics] Fixup of global wiring diagram. [Code_BBB] Translate cross-compilation setup guide to English.
2018-06-03 [BBB-Eurobot] Add Metronome code for precise time handling.
    - Add Metronome struct and functions to enable more precise periodic code execution
    than using standard sleep or g_timeout.
    - Use Metronome in Localisation, where we want to run localisation routine every 10ms.
    The new implementation is much more precise, and does not drift as much (total drift < 0.1%
    against 5% ; note that due to CPU load, the time between two iterations still varies, but
    not as much as before).
    [L6470Driver.c, Localisation.c]
